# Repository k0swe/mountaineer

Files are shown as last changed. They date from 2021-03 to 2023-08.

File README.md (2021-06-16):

This is a build-it-yourself project at the moment. For something productized, see https://digirig.net/!

# Mountaineer logo Mountaineer Radio Interface

This KiCAD project is a schematic for an integrated CAT and audio amateur radio interface. It's
designed with the [Lab599 Discovery TX-500](https://lab599.com/) radio in mind, but the only thing
that makes it radio-specific is the GX12 connectors for CAT and DATA. The rest of the board is a
generic USB-to-serial and audio interface and is suitable for many radios.

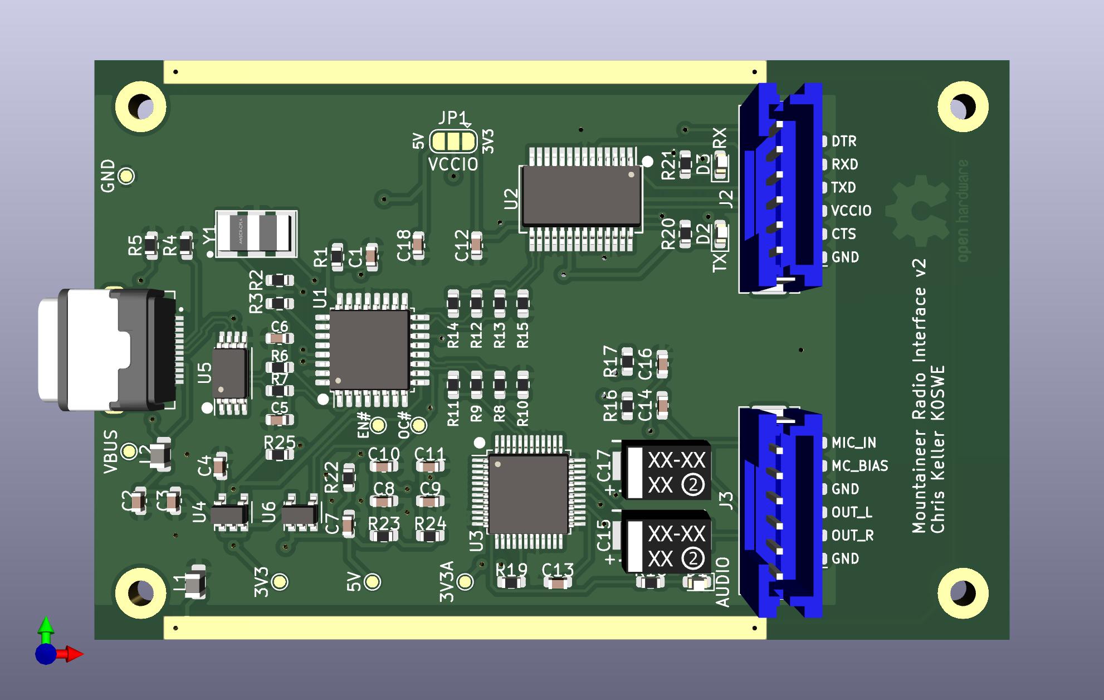
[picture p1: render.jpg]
Render

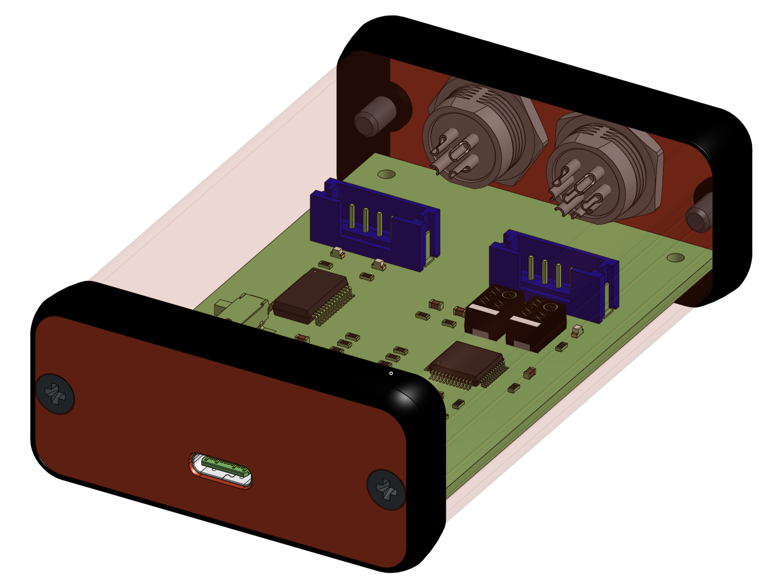
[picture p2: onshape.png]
Onshape


This is somewhat comparable to the Yaesu SCU-17 interface in that it provides both audio
and [CAT control](https://en.wikipedia.org/wiki/Computer_Aided_Transceiver). It is less like the
SignaLink USB interface which only provides audio plus a VOX-based PTT signal but not CAT control.

My design goals are to make this much like the TX-500 itself: small, lightweight and rugged enough
to be outdoors. As such, volume knobs and headphone monitor jacks are not incorporated.

Mechanical CAD drawings are hosted publicly in 
[Onshape](https://cad.onshape.com/documents/40ae2a09f3b2d7950cd3b26d/w/39e0f86d97c1d198a7f9316f/e/2142c3ad4293d2f81a75534e).

## Thank you!

I've received a lot of advice from folks about improvements to this design. Thank you to those who
have helped make this project better!

* Kari Argillander, [@teksturi](https://github.com/teksturi)
* Elías Rodríguez Martín, [@eliasrm87](https://github.com/eliasrm87)
* EEVblog Forum user [mon2](https://www.eevblog.com/forum/profile/?u=690092)
* Dave Maciorowski, [WA1JHK](https://www.qrz.com/db/WA1JHK)
* Nathan Conrad, [@pigrew](https://github.com/pigrew)
* Andreas Jochum, [@ctech4285](https://github.com/ctech4285)
* [The Gizmo Dojo](http://thegizmodojo.com/)
* [Rocky Mountain Ham Radio](https://www.rmham.org/)

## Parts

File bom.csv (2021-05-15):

Refs | value | Manufacturer_Name | Manufacturer_Part_Number | datasheet | footprint | LCSC | Vendor | Vendor Part Number
C1 | 0.1uF |  |  |  | Capacitor_SMD:C_0603_1608Metric | C1588 | LCSC | C1588
C10 | 0.1uF |  |  |  | Capacitor_SMD:C_0603_1608Metric | C1588 | LCSC | C1588
C11 | 0.1uF |  |  |  | Capacitor_SMD:C_0603_1608Metric | C1588 | LCSC | C1588
C12 | 0.1uF |  |  |  | Capacitor_SMD:C_0603_1608Metric | C1588 | LCSC | C1588
C13 | 4.7uF |  |  |  | Capacitor_SMD:C_0603_1608Metric | C19666 | LCSC | C19666
C14 | 1uF |  |  |  | Capacitor_SMD:C_0603_1608Metric | C15849 | LCSC | C15849
C15 | 470uF | Vishay | 293D477X9010E2TE3 | https://datasheet.octopart.com/293D477X9010E2TE3-Vishay-datasheet-5312541.pdf | Vishay:CAPPM7343X430N | C232200 | Mouser | 74-293D477X9010E2TE3
C16 | 4.7uF |  |  |  | Capacitor_SMD:C_0603_1608Metric | C19666 | LCSC | C19666
C17 | 470uF | Vishay | 293D477X9010E2TE3 | https://datasheet.octopart.com/293D477X9010E2TE3-Vishay-datasheet-5312541.pdf | Vishay:CAPPM7343X430N | C232200 | Mouser | 74-293D477X9010E2TE3
C18 | 0.1uF |  |  |  | Capacitor_SMD:C_0603_1608Metric | C1588 | LCSC | C1588
C2 | 4.7uF |  |  |  | Capacitor_SMD:C_0603_1608Metric | C19666 | LCSC | C19666
C3 | 0.1uF |  |  |  | Capacitor_SMD:C_0603_1608Metric | C1588 | LCSC | C1588
C4 | 4.7uF |  |  |  | Capacitor_SMD:C_0603_1608Metric | C19666 | LCSC | C19666
C5 | 22pF |  |  |  | Capacitor_SMD:C_0603_1608Metric | C1653 | LCSC | C1653
C6 | 22pF |  |  |  | Capacitor_SMD:C_0603_1608Metric | C1653 | LCSC | C1653
C7 | 0.1uF |  |  |  | Capacitor_SMD:C_0603_1608Metric | C1588 | LCSC | C1588
C8 | 4.7uF |  |  |  | Capacitor_SMD:C_0603_1608Metric | C19666 | LCSC | C19666
C9 | 4.7uF |  |  |  | Capacitor_SMD:C_0603_1608Metric | C19666 | LCSC | C19666
D1 | AUDIO |  |  |  | LED_SMD:LED_0603_1608Metric | C2286 | LCSC | C2286
D2 | TX |  |  |  | LED_SMD:LED_0603_1608Metric | C2286 | LCSC | C2286
D3 | RX |  |  |  | LED_SMD:LED_0603_1608Metric | C2286 | LCSC | C2286
J1 | USB_C_Receptacle | CUI | UJ31-CH-G-SMT-TR-67 | https://www.mouser.com/datasheet/2/670/uj31_ch_g_smt_tr_67-2306975.pdf | CUI:CUI_UJ31-CH-G-SMT-TR-67 | - | Mouser | 490-UJ31-CH-GSMTTR67
J2 | CAT | JST | B6B-PH-SM4-TB | http://www.farnell.com/datasheets/1699381.pdf | Connector_JST:JST_PH_B6B-PH-SM4-TB_1x06-1MP_P2.00mm_Vertical | C471518 | Newark | 37K9975
J3 | AUDIO | JST | B6B-PH-SM4-TB | http://www.farnell.com/datasheets/1699381.pdf | Connector_JST:JST_PH_B6B-PH-SM4-TB_1x06-1MP_P2.00mm_Vertical | C471518 | Newark | 37K9975
L1 | FB |  |  |  | Inductor_SMD:L_0805_2012Metric | C1017 | LCSC | C1017
L2 | FB |  |  |  | Inductor_SMD:L_0805_2012Metric | C1017 | LCSC | C1017
R1 | 15k |  |  |  | Resistor_SMD:R_0603_1608Metric | C22809 | LCSC | C22809
R10 | 15k |  |  |  | Resistor_SMD:R_0603_1608Metric | C22809 | LCSC | C22809
R11 | 15k |  |  |  | Resistor_SMD:R_0603_1608Metric | C22809 | LCSC | C22809
R12 | 27R |  |  |  | Resistor_SMD:R_0603_1608Metric | C25190 | LCSC | C25190
R13 | 27R |  |  |  | Resistor_SMD:R_0603_1608Metric | C25190 | LCSC | C25190
R14 | 15k |  |  |  | Resistor_SMD:R_0603_1608Metric | C22809 | LCSC | C22809
R15 | 15k |  |  |  | Resistor_SMD:R_0603_1608Metric | C22809 | LCSC | C22809
R16 | 2.2k |  |  |  | Resistor_SMD:R_0603_1608Metric | C4190 | LCSC | C4190
R17 | 1.2k |  |  |  | Resistor_SMD:R_0603_1608Metric | C22765 | LCSC | C22765
R18 | 330R |  |  |  | Resistor_SMD:R_0603_1608Metric | C23137 | LCSC | C23137
R19 | 15k |  |  |  | Resistor_SMD:R_0603_1608Metric | C22809 | LCSC | C22809
R2 | 1.5k |  |  |  | Resistor_SMD:R_0603_1608Metric | C22843 | LCSC | C22843
R20 | 330R |  |  |  | Resistor_SMD:R_0603_1608Metric | C23137 | LCSC | C23137
R21 | 330R |  |  |  | Resistor_SMD:R_0603_1608Metric | C23137 | LCSC | C23137
R22 | 0R |  |  |  | Resistor_SMD:R_0603_1608Metric | C21189 | LCSC | C21189
R23 | 0R |  |  |  | Resistor_SMD:R_0603_1608Metric | C21189 | LCSC | C21189
R24 | 0R |  |  |  | Resistor_SMD:R_0603_1608Metric | C21189 | LCSC | C21189
R25 | 15k |  |  |  | Resistor_SMD:R_0603_1608Metric | C22809 | LCSC | C22809
R3 | 1.5k |  |  |  | Resistor_SMD:R_0603_1608Metric | C22843 | LCSC | C22843
R4 | 5.1k |  |  |  | Resistor_SMD:R_0603_1608Metric | C23186 | LCSC | C23186
R5 | 5.1k |  |  |  | Resistor_SMD:R_0603_1608Metric | C23186 | LCSC | C23186
R6 | 27R |  |  |  | Resistor_SMD:R_0603_1608Metric | C25190 | LCSC | C25190
R7 | 27R |  |  |  | Resistor_SMD:R_0603_1608Metric | C25190 | LCSC | C25190
R8 | 27R |  |  |  | Resistor_SMD:R_0603_1608Metric | C25190 | LCSC | C25190
R9 | 27R |  |  |  | Resistor_SMD:R_0603_1608Metric | C25190 | LCSC | C25190
SW1 | VCCIO | C&K | JS102011SAQN | https://www.ckswitches.com/media/1422/js.pdf | Button_Switch_SMD:SW_SPDT_CK-JS102011SAQN | C221660 | Newark | 35AH0889
U1 | TUSB2036 | TI | TUSB2036VF | http://www.ti.com/lit/ds/symlink/tusb2036.pdf | Package_QFP:LQFP-32_7x7mm_P0.8mm | C43665 | Digikey | 296-27129-1-ND
U2 | FT232RL | FTDI | FT232RL | https://www.ftdichip.com/Support/Documents/DataSheets/ICs/DS_FT232R.pdf | Package_SO:SSOP-28_5.3x10.2mm_P0.65mm | C8690 | LCSC | C8690
U3 | HS-100B | Cmedia | HS-100B | https://datasheet.lcsc.com/szlcsc/1906061502_Cmedia-HS-100B_C371351.pdf | Package_QFP:LQFP-48_7x7mm_P0.5mm | C371351 | Symmetry | HS-100B
U4 | TPS76333 | TI | TPS76333DBV | http://www.ti.com/lit/ds/symlink/tps763.pdf | Package_TO_SOT_SMD:SOT-23-5 | C7100 | LCSC | C7100
U5 | SN75240 | TI | SN75240PW | http://www.ti.com/lit/ds/symlink/sn65220.pdf | Package_SO:TSSOP-8_4.4x3mm_P0.65mm | C7067 | LCSC | C7067
U6 | TPS2041 | TI | TPS2041CDBV | http://www.ti.com/lit/ds/symlink/tps2041.pdf | Package_TO_SOT_SMD:SOT-23-5 | C206041 | LCSC | C206041
Y1 | AWSCR-6.00CPLA | ABRACON | AWSCR-6.00CPLA-C30-T4 | https://componentsearchengine.com/Datasheets/2/AWSCR-6.00CPLA-C30-T4.pdf | Abracon:AWSCR600CPLAC30T4 | - | Newark | 16AH0979
H1 | MountingHole_Pad | - | - | - | MountingHole:MountingHole_2.2mm_M2_Pad | - | - | -
H2 | MountingHole_Pad | - | - | - | MountingHole:MountingHole_2.2mm_M2_Pad | - | - | -
H3 | MountingHole_Pad | - | - | - | MountingHole:MountingHole_2.2mm_M2_Pad | - | - | -
H4 | MountingHole_Pad | - | - | - | MountingHole:MountingHole_2.2mm_M2_Pad | - | - | -
LOGO1 | Logo_Open_Hardware_Small | - | - | - | Symbol:OSHW-Logo2_9.8x8mm_Copper | - | - | -
TP1 | VBUS | - | - | - | TestPoint:TestPoint_Pad_D1.0mm | - | - | -
TP2 | GND | - | - | - | TestPoint:TestPoint_Pad_D1.0mm | - | - | -
TP3 | 3V3 | - | - | - | TestPoint:TestPoint_Pad_D1.0mm | - | - | -
TP4 | 3V3A | - | - | - | TestPoint:TestPoint_Pad_D1.0mm | - | - | -
TP5 | VCCIO | - | - | - | TestPoint:TestPoint_Pad_D1.0mm | - | - | -
TP6 | 5V | - | - | - | TestPoint:TestPoint_Pad_D1.0mm | - | - | -
#J21 | CAT | JST | PHR-6 | https://www.jst-mfg.com/product/pdf/eng/ePH.pdf | - | - | Newark | 92K8052
#J22 | GX12-4P | - | GX12-4P | - | - | - | Amazon | B06XF1SP8M
#J31 | AUDIO | JST | PHR-6 | https://www.jst-mfg.com/product/pdf/eng/ePH.pdf | - | - | Newark | 92K8052
#J32 | GX12-7P | - | GX12-7P | - | - | - | Amazon | B06XF4HXWC
- | Crimped cable | JST | ASPHSPH24K51 | https://www.jst-mfg.com/product/pdf/eng/ePH.pdf | - | - | Digikey | 455-3081-ND
- | Enclosure | Hammond | 1455C801 | https://www.hammfg.com/files/parts/pdf/1455C801.pdf | - | - | Digikey | HM1397-ND

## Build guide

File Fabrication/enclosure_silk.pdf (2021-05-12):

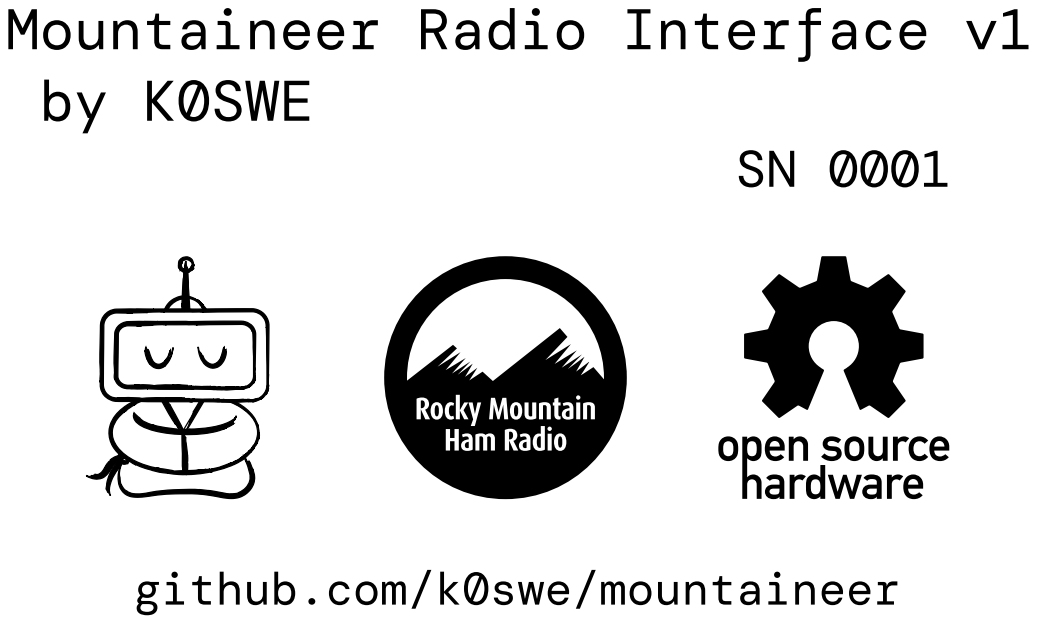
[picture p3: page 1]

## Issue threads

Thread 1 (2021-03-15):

Audio chipset support components?

xylo04, 2021-03-15:
The Cmedia HS-100 datasheet does not include application notes, nor is the eval board schematic published as far as I can find. There are probably more support components needed than I have currently.

I've also heard some debate about using transformers for isolation, similar to [KX4Z's sound card interface](https://www.qsl.net/nf4rc/BookFormSoundCardInterfaceManualFINAL.pdf) (page 10, figure 1-1).

xylo04, 2021-05-03:
This was resolved by building and validating https://github.com/k0swe/cm108b-eval and https://github.com/k0swe/hs100b-eval.

Closed 2021-05-03.

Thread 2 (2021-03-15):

Ferrite beads for USB bus voltage?

xylo04, 2021-03-15:
In the FT232R datasheet, the application notes in sections 6 and 7 suggest using ferrite beads on the USB bus voltage. Maybe this would protect the bus voltage from RF interference? Should I put this just on the two USB ports, or also on the 3.3V line of the CAT connector?

xylo04, 2021-05-12:
This was incorporated.

Closed 2021-05-12.

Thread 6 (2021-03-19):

TPS76333 might be superfluous

xylo04, 2021-03-19:
From teksturi on [eevblog forums](https://www.eevblog.com/forum/oshw/advice-on-a-custom-usb-device/msg3518864/#msg3518864):

"You might even change design that you do not have TPS76333 at all. FT232 can make 3V3 so you can use that to power TUSB2036. Datasheet says you can draw 50mA from that and TUSB2036 use 40mA. I do not know how much J2 other end draws.

"It will be close and is up to you to decide if you wanna use this. If this is my design. I would design it so that I can use both ways. Just add 0ohm resistor from FT232 output to 3V3 rail. If this not work then populate TPS76333. Remember to still add needed caps."

xylo04, 2021-05-12:
I'm going to keep using the TPS76333 to ensure that the current is sufficient.

Closed 2021-05-12.

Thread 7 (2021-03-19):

Make CAT voltage selectable

xylo04, 2021-03-19:
From teksturi on [eevblog forums](https://www.eevblog.com/forum/oshw/advice-on-a-custom-usb-device/msg3518864/#msg3518864):

"I really like idea that FT232 external supply voltage can be
selectable. See datasheet section 6.4. You can use 0ohm resistor
to jumper. Of course this is just idea and I would probably do
this this way."

This isn't necessary for the TX-500, but might be useful for generalizing the design for other radios.

xylo04, 2021-05-05:
Resolved in 175b33e105de24e2894e6f2e916abd9972dedb24

Closed 2021-05-05.

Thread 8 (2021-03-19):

Add LEDs for UART TX/RX, audio chip

xylo04, 2021-03-19:
From teksturi on [eevblog forums](https://www.eevblog.com/forum/oshw/advice-on-a-custom-usb-device/msg3518864/#msg3518864):

"[Re FT232R] Also if you have room in your pcb add leds for tx
and rx. You do not even have to populate these but if something is
not working you can populate them."

"Add led also for [audio chip]. I think you have much room in your pcb."

xylo04, 2021-05-05:
Resolved in 175b33e105de24e2894e6f2e916abd9972dedb24

Closed 2021-05-05.

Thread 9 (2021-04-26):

Use CM108B and expose one of its GPIOs

xylo04, 2021-04-26:
I'm currently using the Cmedia HS100B audio chip. That should work fine for the TX500 in particular since that uses CAT control for PTT. However, to make this device more flexible for other radios, I could use the CM108B which includes GPIO pins that can be used for PTT.

As an example of driving this, Dire Wolf includes a [driver to do PTT](https://github.com/wb2osz/direwolf/blob/fe6cba2b0dfa1f0f6d95bed20301baf1d727a566/src/cm108.c) through the HID protocol.

xylo04, 2021-05-05:
Actually, I think I'll leave this out and stick with the HS100B. For radios that need a PTT signal, it's already common practice to use CTS or DTR on a serial port, so exposing those on the UART is good enough.

Closed 2021-05-05.

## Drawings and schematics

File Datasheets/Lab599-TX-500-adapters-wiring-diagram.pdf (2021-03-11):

# Power cable

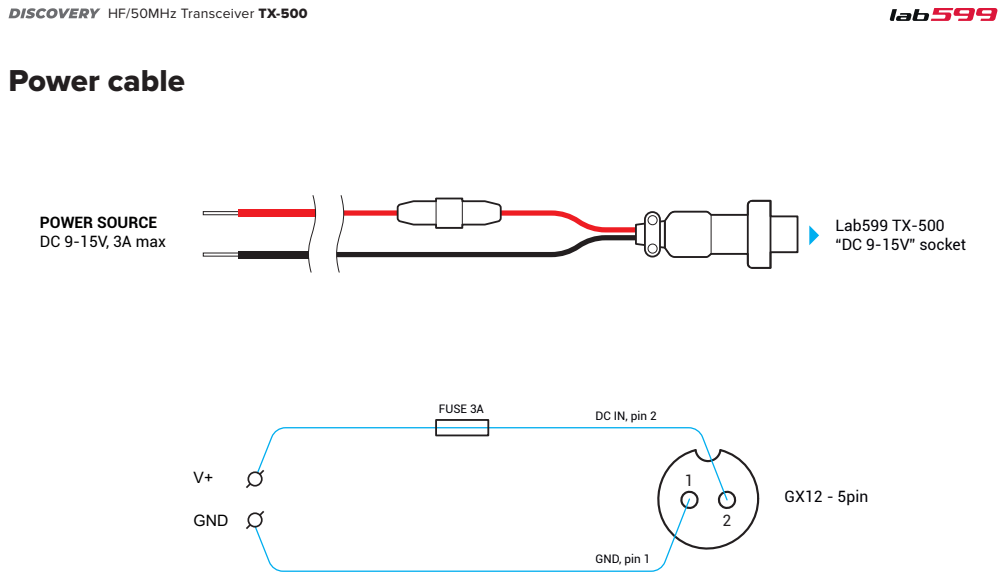
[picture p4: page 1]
GX12 - 5pin; GND, pin 1; GND; FUSE 3A; Lab599 TX-500 “DC 9-15V” socket; POWER SOURCE DC 9-15V, 3A max

HF/50MHz Transceiver TX-500

DC IN, pin 2

# CW key adapter

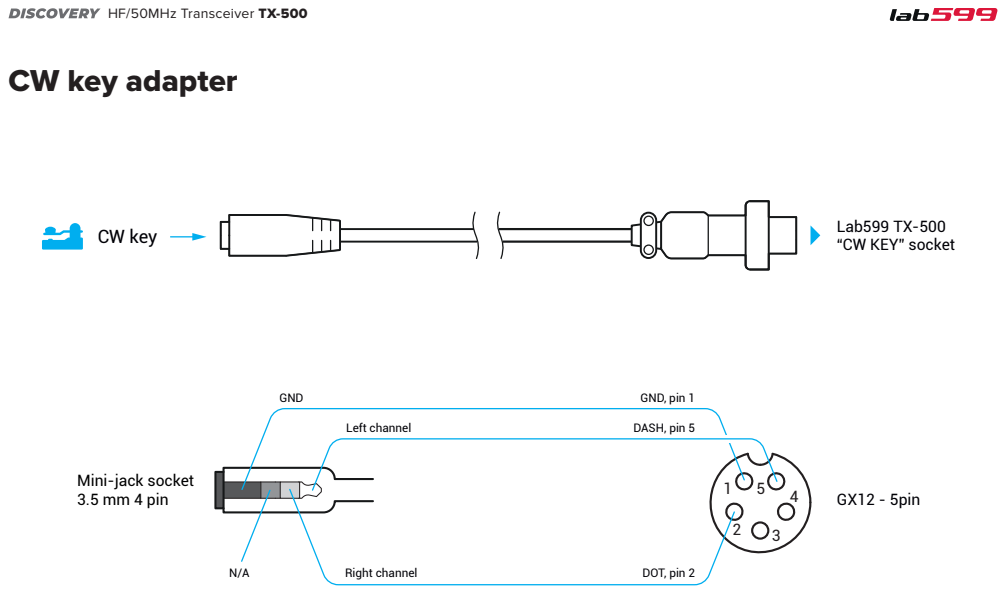
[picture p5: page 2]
3.5 mm 4 pin; GX12 - 5pin; GND; Left channel; Right channel; GND, pin 1; DASH, pin 5; DOT, pin 2; Lab599 TX-500

“CW KEY” socket CW key

Mini-jack socket

# Remote Speaker Microphone

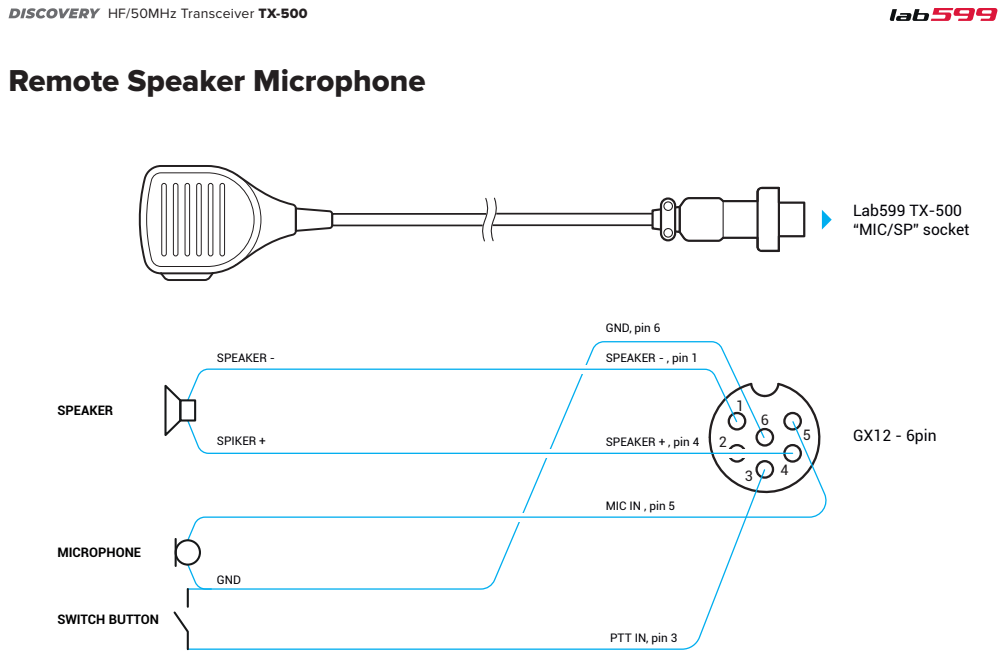
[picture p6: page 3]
SPEAKER -; SPIKER +; GND; MICROPHONE; SPEAKER; SWITCH BUTTON; GND, pin 6; SPEAKER + , pin 4; SPEAKER - , pin 1; GX12 - 6pin

Lab599 TX-500
“MIC/SP” socket

MIC IN , pin 5

PTT IN, pin 3

# MIC/SP/PTT adapter

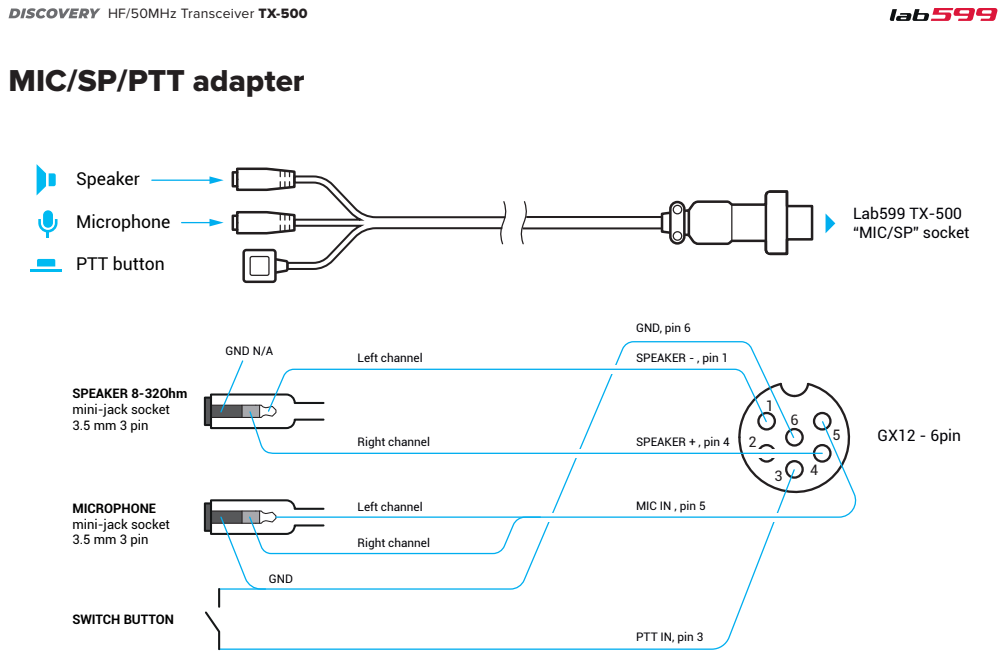
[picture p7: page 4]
GX12 - 6pin; Speaker; Microphone; PTT button; SWITCH BUTTON; Left channel; Right channel; GND; GND, pin 6; SPEAKER + , pin 4

Lab599 TX-500
“MIC/SP” socket

SPEAKER - , pin 1 GND N/A

SPEAKER 8-32Ohm
mini-jack socket
3.5 mm 3 pin

MICROPHONE

MIC IN , pin 5

PTT IN, pin 3

# Dynamic microphone

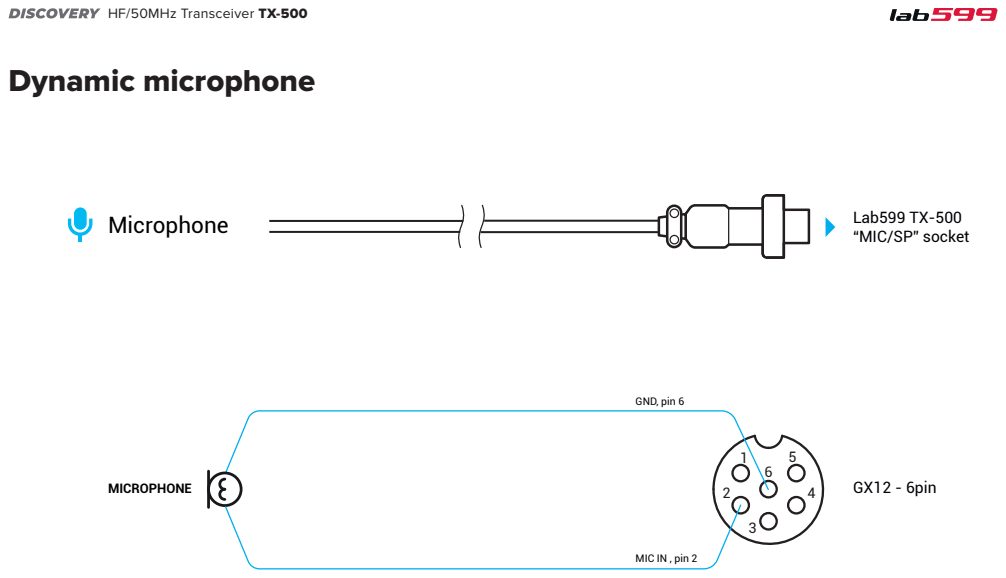
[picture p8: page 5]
GND, pin 6; Microphone; Lab599 TX-500; MICROPHONE; GX12 - 6pin

“MIC/SP” socket

MIC IN , pin 2

# Audio data cable PC audio panel

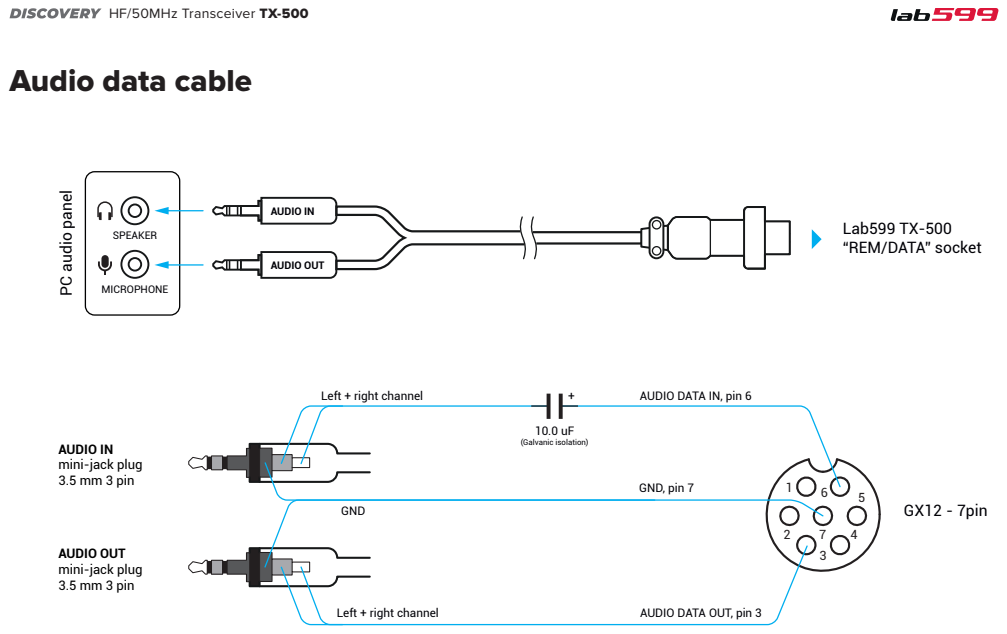
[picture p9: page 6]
10.0 uF (Galvanic isolation); GND; GND, pin 7; GX12 - 7pin; AUDIO OUT; AUDIO IN; SPEAKER; MICROPHONE

Lab599 TX-500
“REM/DATA” socket

Left + right channel

AUDIO DATA IN, pin 6

AUDIO IN
mini-jack plug
3.5 mm 3 pin

AUDIO OUT

AUDIO DATA OUT, pin 3

# CAT-USB adapter

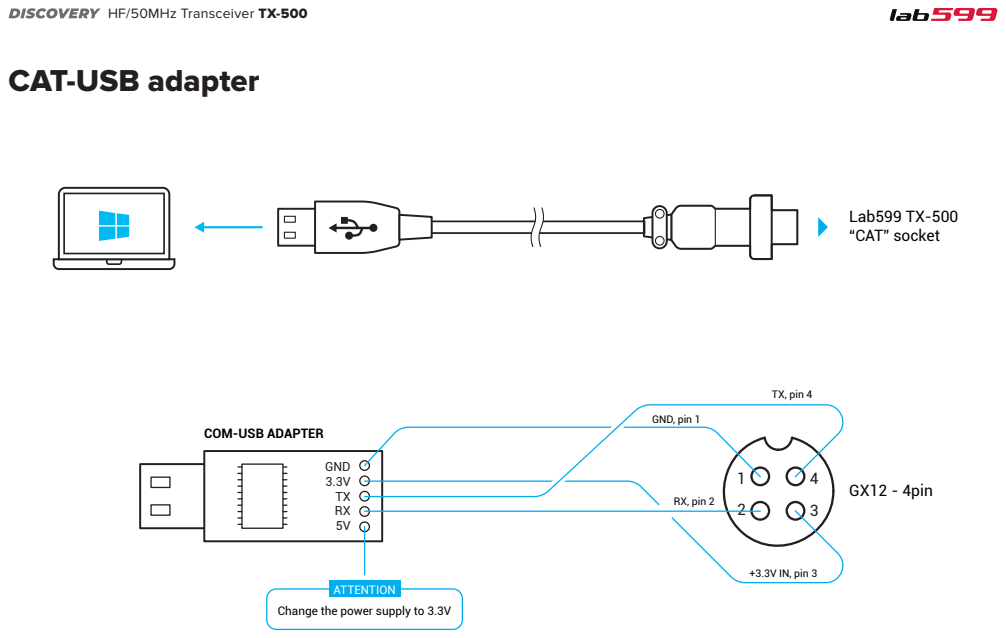
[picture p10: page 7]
GND 3.3V TX RX 5V; GND, pin 1; TX, pin 4; RX, pin 2; +3.3V IN, pin 3; ATTENTION; Lab599 TX-500 “CAT” socket; GX12 - 4pin

COM-USB ADAPTER

Сhange the power supply to 3.3V

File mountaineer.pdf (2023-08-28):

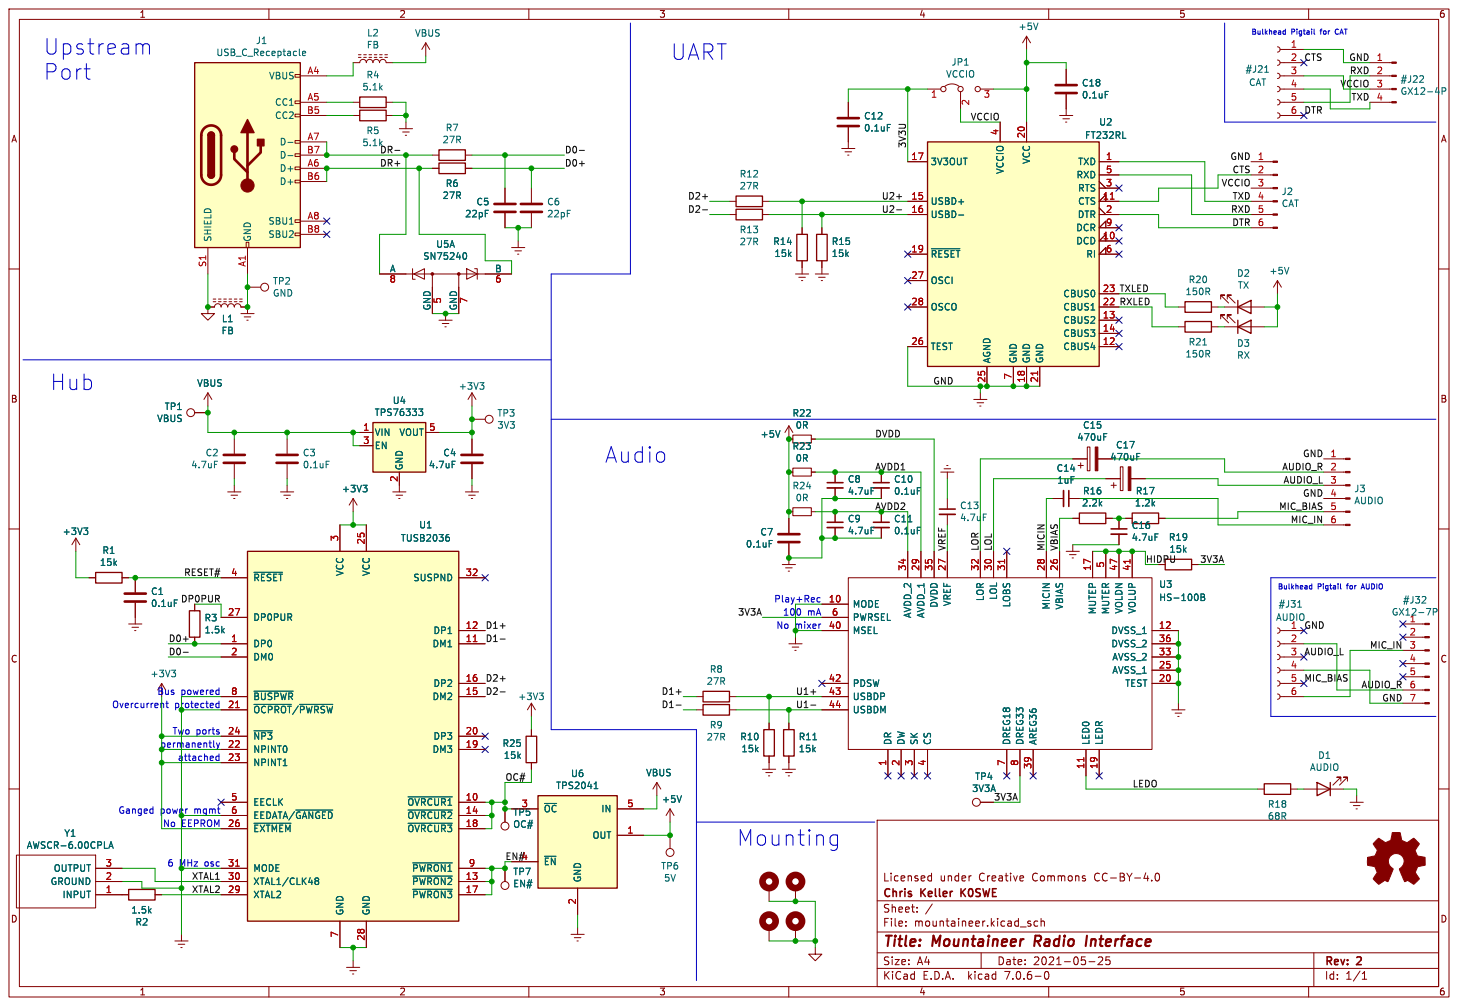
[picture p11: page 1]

100 mA No mixer UART

3 XTAL1/CLK48 30 MODE 31 SUSPND 32 ~{RESET} 4 EECLK 5 EEDATA/~{GANGED} 6 GND

1 MODE 10 LED0 11 DVSS_1 12 MUTEP 17 LEDR 19 DW

4 MSEL 40 VOLUP 41 PDSW 42 USBDP 43 USBDM 44 VOLDN 47 MUTER

2 TEST 20 AVSS_1 25 VBIAS 26 VREF 27 MICIN 28 AVDD_1 29 SK

3 LOL 30 LOBS 31 LOR 32 AVSS_2 33 AVDD_2 34 DVDD 35 DVSS_2 36 AREG36 39 CS

DP0PUR
Play+Rec Two ports permanently Bus powered

Id: 1/1 Title: Mountaineer Radio Interface

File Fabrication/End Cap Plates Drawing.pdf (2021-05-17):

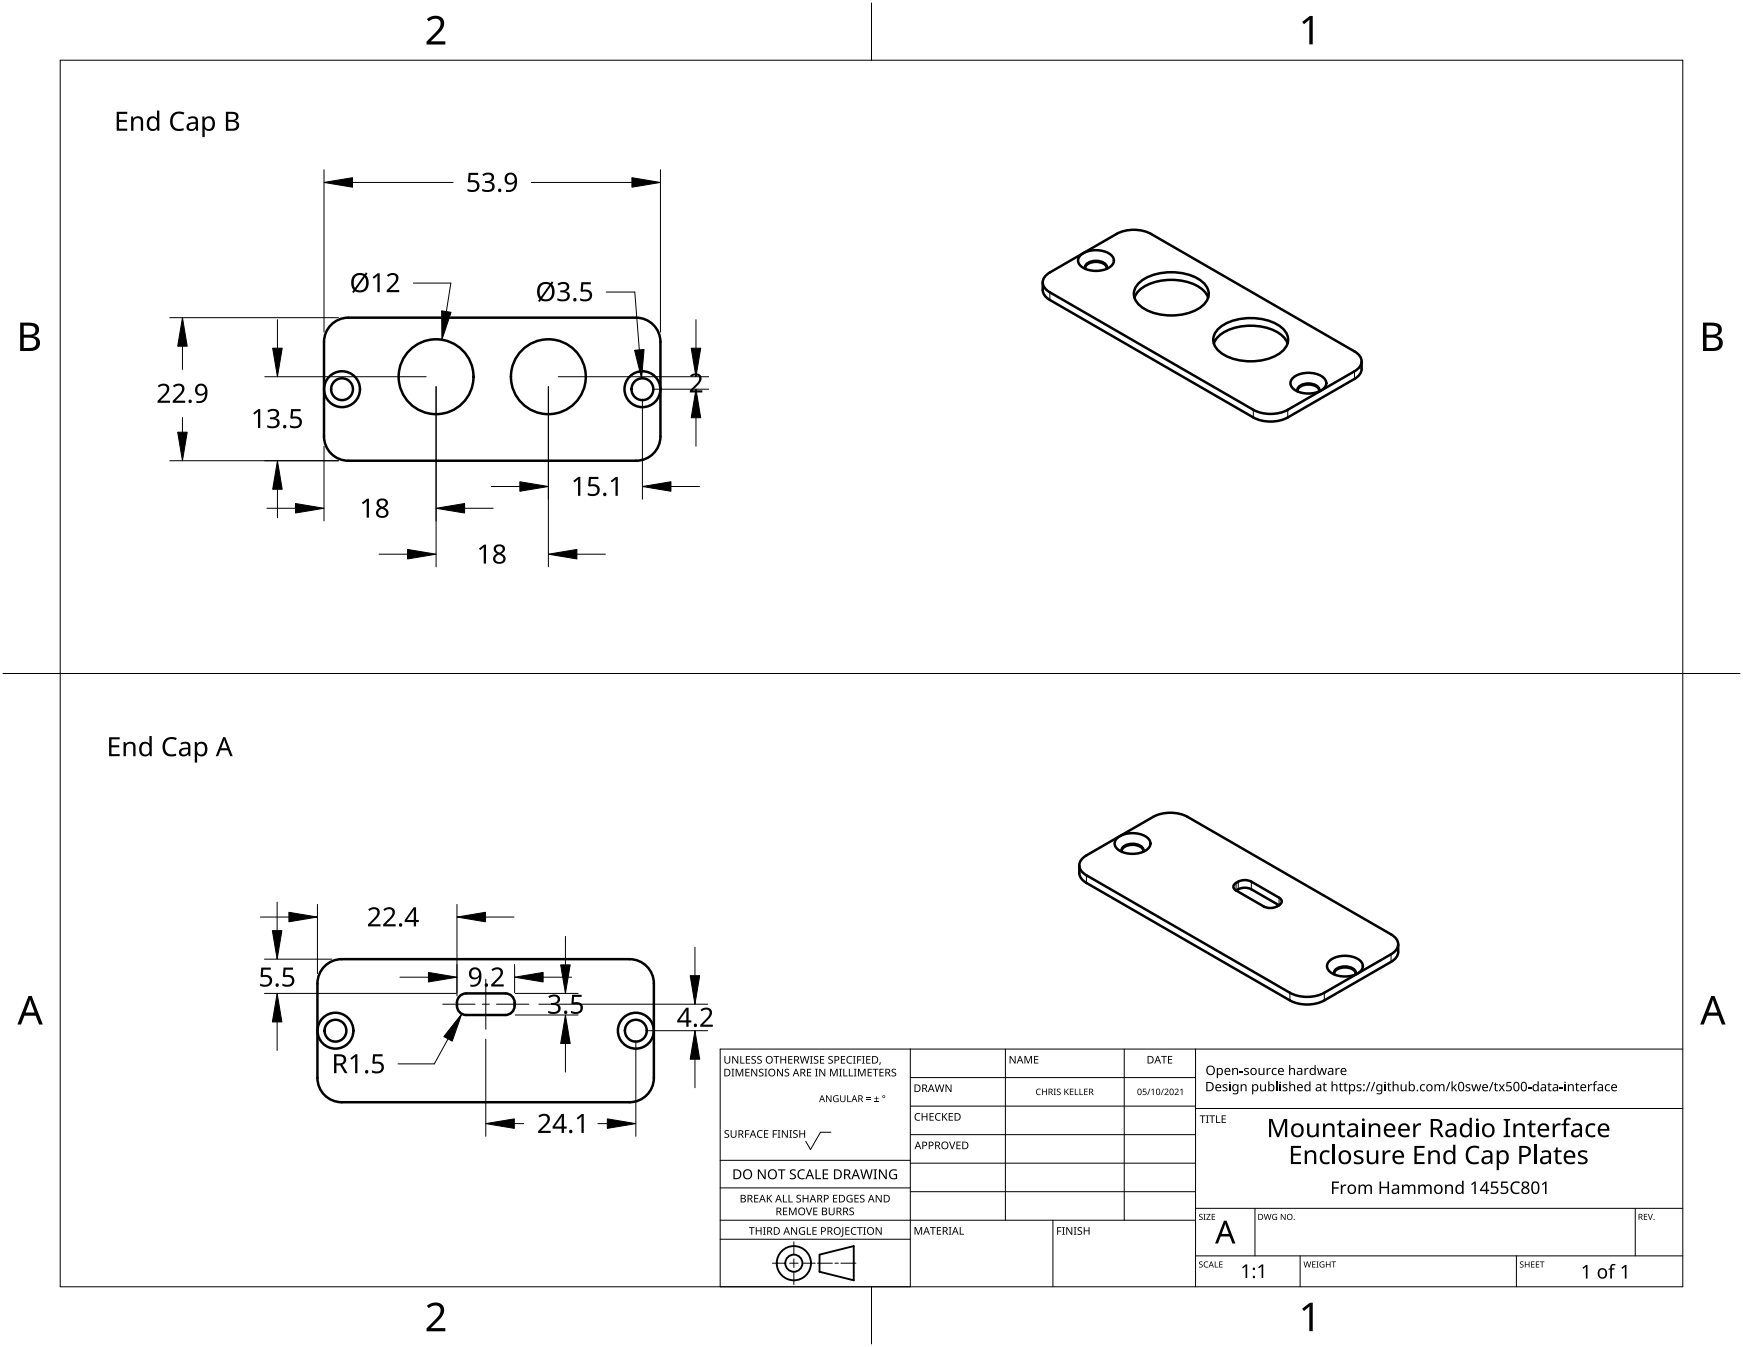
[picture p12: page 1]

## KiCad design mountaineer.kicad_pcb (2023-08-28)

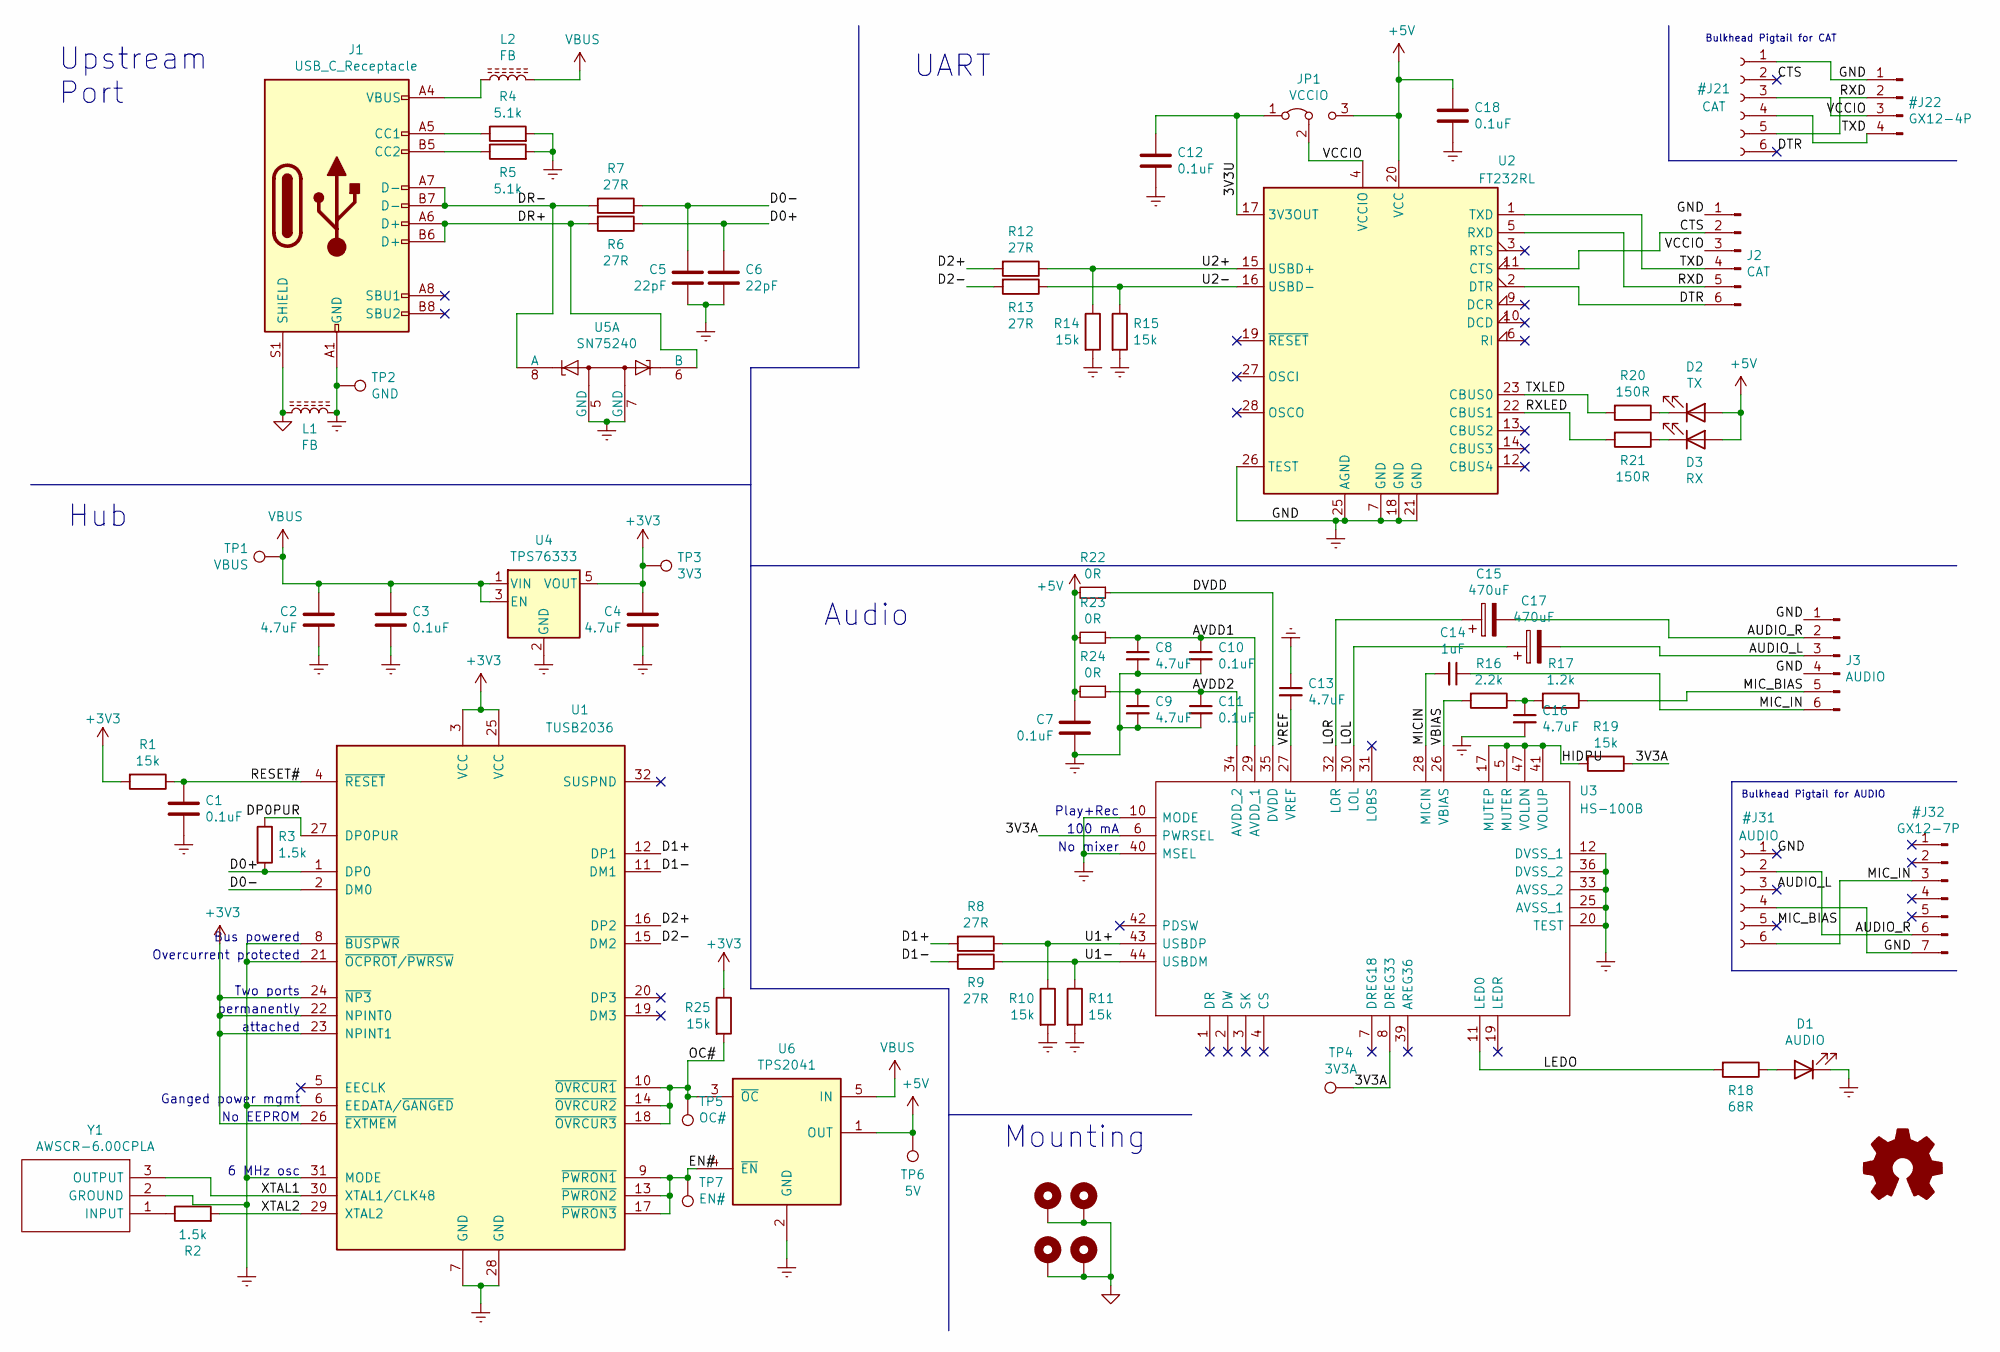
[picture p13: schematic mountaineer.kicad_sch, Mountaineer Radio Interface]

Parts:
C1, C3, C7, C10, C11, C12, C18: 0.1uF; C_0603_1608Metric; LCSC C1588
C2, C4, C8, C9, C13, C16: 4.7uF; C_0603_1608Metric; LCSC C19666
C5, C6: 22pF; C_0603_1608Metric; LCSC C1653
C14: 1uF; C_0603_1608Metric; LCSC C15849
C15, C17: 470uF; CAPPM7343X430N; Manufacturer_Part_Number 293D477X9010E2TE3; LCSC C232200
D1: AUDIO; LED_0603_1608Metric; LCSC C2286
D2: TX; LED_0603_1608Metric; LCSC C2286
D3: RX; LED_0603_1608Metric; LCSC C2286
H1, H2, H3, H4: MountingHole_Pad; MountingHole_2.2mm_M2_Pad
J1: USB_C_Receptacle; CUI_UJ31-CH-G-SMT-TR-67; Manufacturer_Part_Number UJ31-CH-G-SMT-TR-67
J2: CAT; JST_PH_B6B-PH-SM4-TB_1x06-1MP_P2.00mm_Vertical; Manufacturer_Part_Number B6B-PH-SM4-TB; LCSC C471518
J3: AUDIO; JST_PH_B6B-PH-SM4-TB_1x06-1MP_P2.00mm_Vertical; Manufacturer_Part_Number B6B-PH-SM4-TB; LCSC C471518
JP1: VCCIO; SolderJumper-3_P1.3mm_Bridged12_RoundedPad1.0x1.5mm
L1, L2: FB; L_0805_2012Metric; LCSC C1017
LOGO1: Logo_Open_Hardware_Small; OSHW-Logo2_9.8x8mm_Copper
R1, R10, R11, R14, R15, R19, R25: 15k; R_0603_1608Metric; LCSC C22809
R2, R3: 1.5k; R_0603_1608Metric; LCSC C22843
R4, R5: 5.1k; R_0603_1608Metric; LCSC C23186
R6, R7, R8, R9, R12, R13: 27R; R_0603_1608Metric; LCSC C25190
R16: 2.2k; R_0603_1608Metric; LCSC C4190
R17: 1.2k; R_0603_1608Metric; LCSC C22765
R18: 68R; R_0603_1608Metric; LCSC C27592
R20, R21: 150R; R_0603_1608Metric; LCSC C22808
R22, R23, R24: 0R; R_0603_1608Metric; LCSC C21189
TP1: VBUS; TestPoint_Pad_D1.0mm
TP2: GND; TestPoint_Pad_D1.0mm
TP3: 3V3; TestPoint_Pad_D1.0mm
TP4: 3V3A; TestPoint_Pad_D1.0mm
TP5: OC#; TestPoint_Pad_D1.0mm
TP6: 5V; TestPoint_Pad_D1.0mm
TP7: EN#; TestPoint_Pad_D1.0mm
U1: TUSB2036; LQFP-32_7x7mm_P0.8mm; Manufacturer_Part_Number TUSB2036VF; LCSC C43665
U2: FT232RL; SSOP-28_5.3x10.2mm_P0.65mm; Manufacturer_Part_Number FT232RL; LCSC C8690
U3: HS-100B; LQFP-48_7x7mm_P0.5mm; Manufacturer_Part_Number HS-100B; LCSC C371351
U4: TPS76333; SOT-23-5; Manufacturer_Part_Number TPS76333DBV; LCSC C7100
U5: SN75240; TSSOP-8_4.4x3mm_P0.65mm; Manufacturer_Part_Number SN75240PW; LCSC C7067
U6: TPS2041; SOT-23-5; Manufacturer_Part_Number TPS2041CDBV; LCSC C206041
Y1: AWSCR-6.00CPLA; AWSCR600CPLAC30T4; Manufacturer_Part_Number AWSCR-6.00CPLA-C30-T4

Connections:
+3V3: C4.1, R1.2, R25.1, TP3.1, U1.3 (VCC), U1.22 (NPINT0), U1.23 (NPINT1), U1.24 (~NP3), U1.25 (VCC), U1.26 (~EXTMEM), U4.5 (VOUT)
+5V: C7.1, C18.1, D2.2 (A), D3.2 (A), JP1.3 (B), R22.2, R23.2, R24.2, TP6.1, U2.20 (VCC), U6.1 (OUT)
/3V3A: R19.1, TP4.1, U3.6 (PWRSEL), U3.8 (DREG33)
/3V3U: C12.1, JP1.1 (A), U2.17 (3V3OUT)
/AVDD1: C8.1, C10.1, R23.1, U3.29 (AVDD_1)
/AVDD2: C9.1, C11.1, R24.1, U3.34 (AVDD_2)
/D0+: C6.1, R3.2, R6.1, U1.1 (DP0)
/D0-: C5.1, R7.1, U1.2 (DM0)
/D1+: R8.2, U1.12 (DP1)
/D1-: R9.2, U1.11 (DM1)
/D2+: R12.2, U1.16 (DP2)
/D2-: R13.2, U1.15 (DM2)
/DP0PUR: R3.1, U1.27 (DP0PUR)
/DR+: J1.A6 (D+), J1.B6 (D+), R6.2, U5.6 (B)
/DR-: J1.A7 (D-), J1.B7 (D-), R7.2, U5.8 (A)
/DVDD: R22.1, U3.35 (DVDD)
/EN#: TP7.1, U1.9 (~PWRON1), U1.13 (~PWRON2), U1.17 (~PWRON3), U6.4 (~EN)
/HIDPU: R19.2, U3.5 (MUTER), U3.17 (MUTEP), U3.41 (VOLUP), U3.47 (VOLDN)
/LEDO: R18.2, U3.11 (LED0)
/LOL: C17.1, U3.30 (LOL)
/LOR: C15.1, U3.32 (LOR)
/MICIN: C14.2, U3.28 (MICIN)
/OC#: R25.2, TP5.1, U1.10 (~OVRCUR1), U1.14 (~OVRCUR2), U1.18 (~OVRCUR3), U6.3 (~OC)
/RESET#: C1.1, R1.1, U1.4 (~RESET)
/RXLED: R21.2, U2.22 (CBUS1)
/TXLED: R20.2, U2.23 (CBUS0)
/U1+: R8.1, R10.1, U3.43 (USBDP)
/U1-: R9.1, R11.1, U3.44 (USBDM)
/U2+: R12.1, R14.1, U2.15 (USBD+)
/U2-: R13.1, R15.1, U2.16 (USBD-)
/VBIAS: R16.2, U3.26 (VBIAS)
/VREF: C13.2, U3.27 (VREF)
/XTAL1: U1.30 (XTAL1/CLK48), Y1.3 (OUTPUT)
/XTAL2: R2.2, U1.29 (XTAL2)
GND1: H1.1, H2.1, H3.1, H4.1, J1.S1 (SHIELD), L1.1
unnamed: C16.1, R16.1, R17.2
unnamed: D1.2 (A), R18.1
unnamed: D2.1 (K), R20.1
unnamed: D3.1 (K), R21.1
unnamed: J1.A4 (VBUS), J1.A9 (VBUS), J1.B4 (VBUS), J1.B9 (VBUS), L2.1
unnamed: J1.A5 (CC1), R4.1
unnamed: J1.B5 (CC2), R5.1
unnamed: R2.1, Y1.1 (INPUT)
VBUS: C2.1, C3.1, L2.2, TP1.1, U4.1 (VIN), U4.3 (EN), U6.5 (IN)

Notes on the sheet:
Bulkhead Pigtail for AUDIO
No mixer
Hub
Upstream Port
Audio
Ganged power mgmt
permanently
UART
attached
Play+Rec
Bulkhead Pigtail for CAT
No EEPROM
6 MHz osc
100 mA
Bus powered
Two ports
Overcurrent protected
Mounting

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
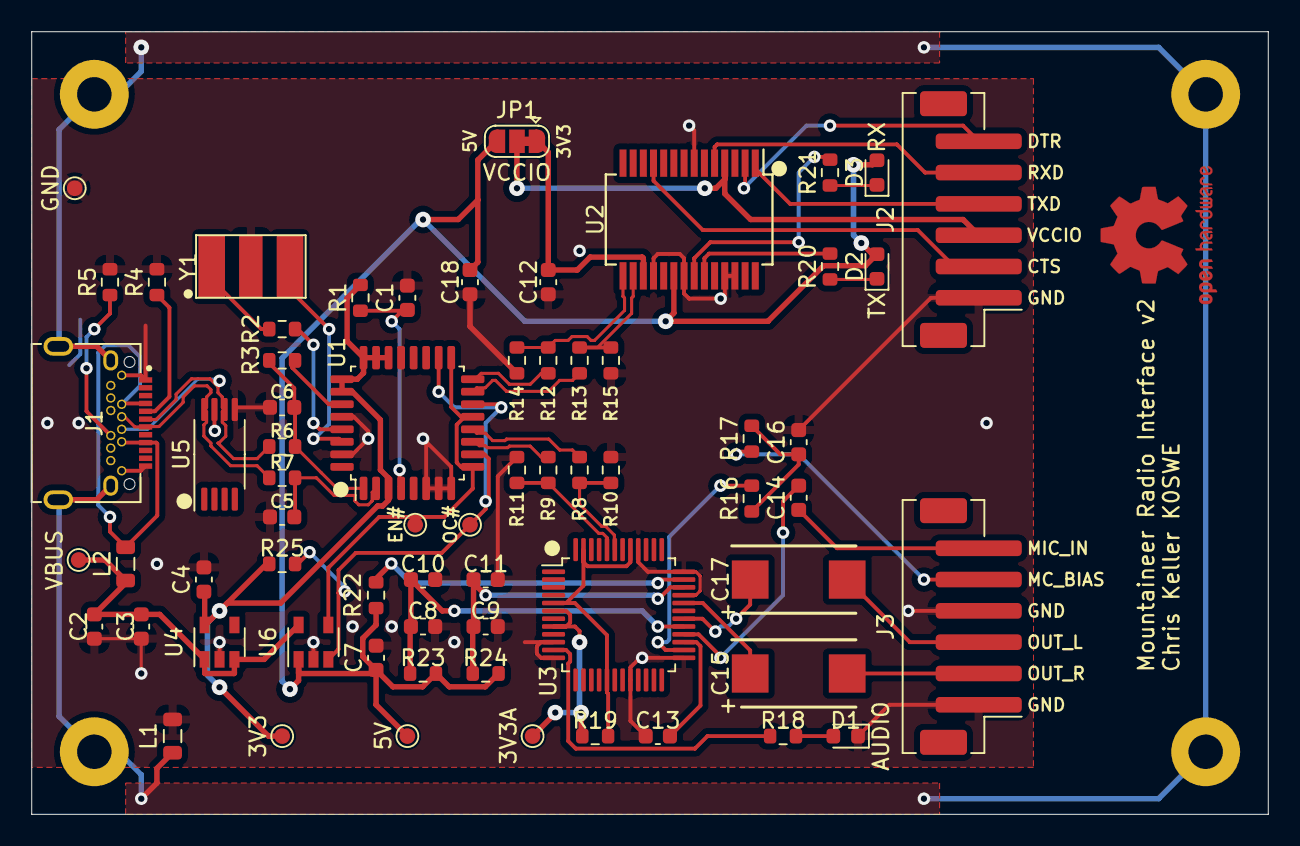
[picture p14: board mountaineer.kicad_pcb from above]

Board: 2 copper layers, 79.0 x 50.0 mm, 71 parts (0 on the bottom side), 54 nets.

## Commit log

2021-03-11 Add basic building blocks and datasheets
    [tx500-data.sch]
2021-03-11 Start using heirarchical pages, and progress on subsystems
    [AudioInterface.sch, CatControl.sch, DownstreamUSB.sch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]
2021-03-12 Moved clock to its own page
    [AudioInterface.sch, CatControl.sch, Clock.sch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]
2021-03-12 First pass at audio
    [AudioInterface.sch, CatControl.sch, DownstreamUSB.sch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]
2021-03-12 First pass at pcb layout
    Not really ready to set that in stone, but wanted to get an idea of what size enclosure will work.
    [AudioInterface.sch, CatControl.sch, Clock.sch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]
2021-03-14 Swap TUSB4041I for TUSB2036
    The 4041 does more than I need it to, so use the 2036 instead.
    [AudioInterface.sch, CatControl.sch, Clock.sch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]
2021-03-14 Add BOM and clarify some footprints
    [AudioInterface.sch, CatControl.sch, Clock.sch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]
2021-03-14 Add BOM details
    [AudioInterface.sch, CatControl.sch, Clock.sch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]
2021-03-14 Replace 100 uF caps
    The ones I had selected before were only rated for 4V, and I need at least 5V (USB bus).
    [AudioInterface.sch, CatControl.sch, DownstreamUSB.sch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]
2021-03-15 Add a 15mm buffer for the GX12 bulkhead connectors
    [AudioInterface.sch, CatControl.sch, Clock.sch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]
2021-03-15 Add ID markings on schema and pcb
    [AudioInterface.sch, CatControl.sch, Clock.sch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]
2021-03-15 First pass at routing PCB
    [AudioInterface.sch, CatControl.sch, Clock.sch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]
2021-03-15 Replace USB-A port with SMD
    [AudioInterface.sch, CatControl.sch, DownstreamUSB.sch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]
2021-03-16 Adjust USB connectors to start case CAD
    [UpstreamUSB.sch, kifield-bom.csv, tx500-data.kicad_pcb]
2021-03-18 Reorganize onto one page
    Suggested by eevblog.com/forum user teksturi, with thanks! https://www.eevblog.com/forum/oshw/advice-on-a-custom-usb-device/msg3518118/#msg3518118
    [AudioInterface.sch, CatControl.sch, Clock.sch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]
2021-03-18 Add render
    [tx500-data.kicad_pcb]
2021-03-19 Fix floating pins
    [kifield-bom.csv, tx500-data.kicad_pcb, tx500-data.sch]
2021-03-19 Add case ground
    [tx500-data.kicad_pcb, tx500-data.sch]
2021-03-19 Clean up HS-100B pins
    Add test points
    [tx500-data.kicad_pcb, tx500-data.sch]
2021-03-19 Avoid schematic cross-junction
    [tx500-data.sch]
2021-03-19 Move back case ground strip
    [tx500-data.kicad_pcb]
2021-03-19 Add ESD and overcurrent protection
    [tx500-data.kicad_pcb, tx500-data.sch]
2021-03-20 Move 2mm away from enclosure sides
    [tx500-data.kicad_pcb, tx500-data.sch]
2021-03-23 Incorporate advice
    * Remove 120uF decoupling cap for J1
    * Pull up EN4 to disable OUT4
    * Add 0ohm resistors to L/R audio lines in case I need them
    * Also, move components farther away from the enclosure edges
    [bom.csv, tx500-data.kicad_pcb, tx500-data.sch]
2021-03-23 Update assets
    [tx500-data.kicad_pcb]
2021-04-01 Fix JST part number
    Adafruit 4392 is horizontal, not vertical.
    [bom.csv]
2021-04-01 Change 4-pin JST cable
    I can't find any 4-pin cables with no termination, and this one is cheaper.
    [bom.csv]
2021-04-01 Even cheaper 4-pin JST cable
    [bom.csv]
2021-04-02 Add 3D models, and various cleanup
    [tx500-data.kicad_pcb, tx500-data.sch]
2021-04-02 Fix crystal BOM and footprint
    [bom.csv, tx500-data.kicad_pcb, tx500-data.sch]
2021-04-03 Use standard footprint for crystal
    [bom.csv, tx500-data.kicad_pcb, tx500-data.sch]
2021-04-04 Convert BOM from one per line to grouped
    [bom.csv]
2021-04-04 Use smaller dimensions capacitor
    [bom.csv, tx500-data.kicad_pcb, tx500-data.sch]
2021-04-04 Fix BOM
    [bom.csv]
2021-04-05 Fix part properties
    [tx500-data.sch]
2021-04-05 Thicker 5V traces and clean up case grounds
    [tx500-data.kicad_pcb, tx500-data.sch]
2021-04-15 Change license to CC-BY-4.0
    CC is more conducive to open hardware than Apache
    [tx500-data.kicad_pcb, tx500-data.sch]
2021-04-24 Remove unused OSHW logos and use basic ones
    [tx500-data.kicad_pcb]
2021-05-05 Massive rework based on experience with demo boards
    [bom.csv, tx500-data.sch]
2021-05-05 Clean up libraries
    Since I'm spec'ing the Abracon AWSCR-CPLA resonator instead of a crystal, this resolves #5.
    [tx500-data.sch]
2021-05-05 Most footprint assignments after big rework
    [tx500-data.sch]
2021-05-05 Add CUI USB C connector
    [tx500-data.sch]
2021-05-05 Start populating new layout
    [tx500-data.kicad_pcb, tx500-data.sch]
2021-05-05 Start routing traces
    [tx500-data.kicad_pcb]
2021-05-06 Route most of the board
    Still need to check design rules
    [tx500-data.kicad_pcb, tx500-data.sch]
2021-05-06 Rotate UART and fix 3D images
    [tx500-data.kicad_pcb, tx500-data.sch]
2021-05-06 Clean up 3D a bit
    [tx500-data.kicad_pcb]
2021-05-06 Start prepping fabrication
    [jlcpcb_bom.csv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]
2021-05-06 Fix up fabrication files
    [jlcpcb_bom.csv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]
2021-05-06 Add more LCSC part numbers
    [jlcpcb_bom.csv, tx500-data.sch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]
2021-05-07 Add BOM
    [bom.csv, tx500-data.kicad_pcb, tx500-data.sch]
2021-05-08 Fix USB-C footprint
    During fabrication review, the production engineer noticed that the 5V trace intersected with the shield pads. This was because they were using F.CU and B.CU graphics which weren't getting included in the pad margins.
    [tx500-data-B_Cu.gbr, tx500-data-B_Mask.gbr, tx500-data-B_SilkS.gbr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]
2021-05-10 Add Onshape details
    Also add enclosure and GX12 connectors back to BOM
    [bom.csv]
2021-05-11 Add initial enclosure artwork
2021-05-12 Fix up enclosure artwork
2021-05-12 Add bulkhead parts to schematic
    [bom.csv, tx500-data.kicad_pcb, tx500-data.sch]
2021-05-12 Rename project
    [mountaineer-B_Cu.gbr, mountaineer-B_Mask.gbr, mountaineer-B_SilkS.gbr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]
2021-05-15 Add pullup resistor to overcurrent protection
    [bom.csv, jlcpcb_bom.csv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]
2021-05-16 Update end cap plate drawing
2021-05-25 Join all Enable and Overcurrent signals
    I think this is the problem that has been bothering me for several weeks. When I replaced the TPS2044B with the TPS2041B, I thought I could use any Enable and any Overcurrent signal, but in that configuration the hub would refuse to power on the downstream ports. After testing this with a breadboard, I think this is the solution.
    [mountaineer-B_Cu.gbr, mountaineer-B_Mask.gbr, mountaineer-B_SilkS.gbr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]
2021-05-26 Remove VCCIO switch and add more test points
    [jlcpcb_bom.csv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]
2023-08-28 Convert to Kicad 7 project
    [mountaineer-B_Cu.gbr, mountaineer-B_Mask.gbr, mountaineer-B_Silkscreen.gbr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]

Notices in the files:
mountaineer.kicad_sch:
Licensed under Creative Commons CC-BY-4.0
